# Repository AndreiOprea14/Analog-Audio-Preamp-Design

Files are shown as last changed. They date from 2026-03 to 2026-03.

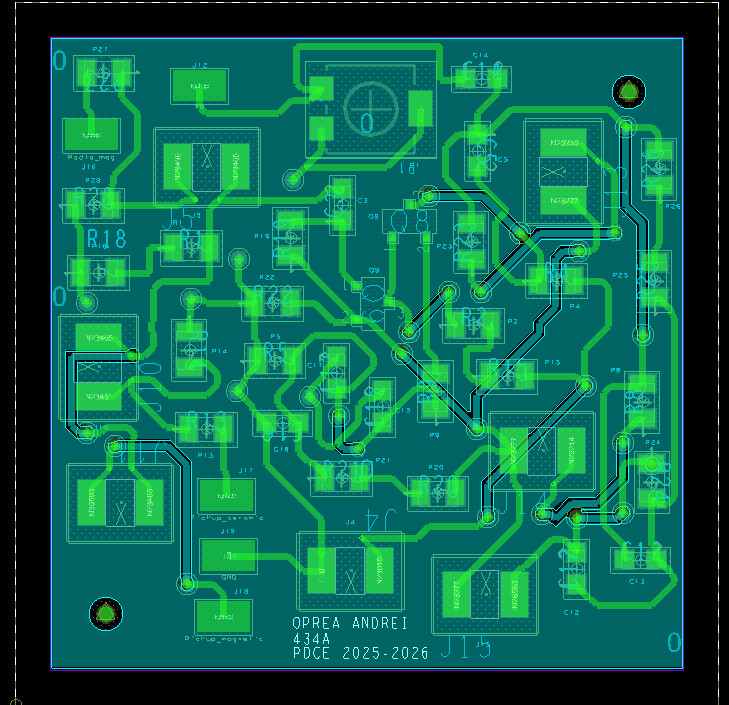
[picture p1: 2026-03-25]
Layout/layout_pcb.jpg

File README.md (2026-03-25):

#  Audio Input Preamplifier & PCB Design

This repository contains the complete design, simulation, and physical layout files for an analog audio input preamplifier with a regulated power supply. It was built as a university hardware project, taking a theoretical schematic all the way to manufacturing-ready files.

## What's this about?
Instead of just doing the math on paper, I had to adapt a base schematic to meet a strictly customized set of parameters (tuning the circuit for a 200mV input sensitivity and a 1000 kOhm input impedance, typical for a ceramic pick-up). 

The engineering process involved:
* **Circuit Simulation:** Before routing anything, I validated the stability and performance of the Class-A amplifier stages using transient and frequency response simulations.
* **Component Substitution:** Swapping out theoretical parts for physically available counterparts (like the BC109C transistors) and making sure the math still checks out.
* **PCB Layout:** Moving from the schematic to **OrCAD PCB Editor**, where I managed trace routing, component placement, and via configurations.

## Tools Used
* **OrCAD Capture CIS** (for schematics and SPICE simulation)
* **OrCAD PCB Editor** (for the physical board layout)

## Project Showcase

schematic

layout_pcb

## What's in this repo?
If you want to check out the technical details, you'll find:
* **Project Documentation:** Detailed math, component choices, and simulation graphs (Transient & Bode plots).
* **Bill of Materials (BOM):** The exact list of resistors, capacitors, transistors, and power supply components used to build the circuit.
* **Gerber Files:** The exported manufacturing files, ready to be sent to a PCB fab.

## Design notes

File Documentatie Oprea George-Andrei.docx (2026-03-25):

Universitatea “Politehnica” din București

Facultatea de Electronică, Telecomunicații si Tehnologia Informației

PROIECT 1:

PREAMPLIFICATOR AUDIO DE INTRARE

CAPITOLUL 5

Student: Oprea George-Andrei

Grupa: 434A

Prof. coordonator

BABARADA Florin

Bucuresti, 2025

1) TEMA DE PROIECTARE

Tema de proiectare prezintă un preamplificator audio de audiofrecvenţă de intrare având schema bloc prezentată în Figura 1. Amplificatorul audio de intrare este compus din o reţea de adaptare la intrare cu principalele surse de semnale audio fiind pick-up cu doză ceramică şi două etaje de amplificare în clasa A, respectiv etajul de intrare şi etajul de ieşire care realizează amplificarea în tensiune a semnalului.

Amplificarea globală a amplificatorului audio de intrare este stabilită de reacţie negativă serie la intrare-paralel la ieşire, iar alimentarea celor 2 etaje de amplificare este realizată de sursa de alimentare.

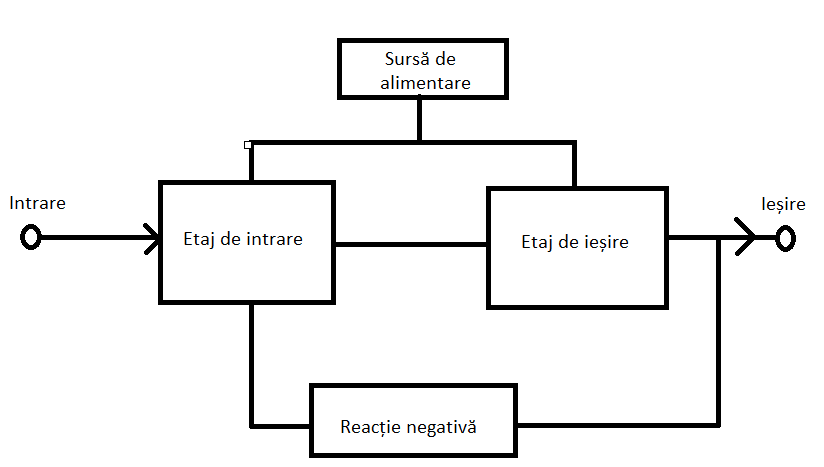
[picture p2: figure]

Figura 1. Schema bloc a preamplificatorului audio de intrare

2) DATE DE INTRARE

Principalii parametrii de intare ai amplificatorului audio sunt:

  - Sensibilitatea minimă la intare Vin (mV)
  - Rezistența de intrare Rin(kOhm)
  - Rezistența de ieșire maximă R0M(kOhm)
  - Tensiunea nominală la ieșirea amplificatorului audio de putere Vn (Vef)

Valorile folosite pentru proiectarea amplificatorului pot fi consultate în tabelul următor:

Nr. crt | Vin [ mV ] | Rin [ kΩ ] | R0M [ kΩ ] | Vn [ Vef ]
12 | 200 | 1000 | 5 | 1,3

3) SCHEMA ELECTRONICĂ

Preamplificatorul este partea care infulențează cel mai pregnant raportul semnal zgomot, caracteristica de frecvență și factorul de distorsiuni într-un lanț de amplificare audiofrecvență.

În practică există adesea și alte semnale numite semnale false, care tind să interfereze cu semnalele dorite și acestea se numesc în general semnale de zgomot.

Un preamplificator sensibil și relativ zgomotos constituie o problemă importantă dacă urmează ca la ieșire zgomotul să fie minim, deoarece orice zgomot din preamplificator este amplificat de fiecare etaj care urmează.

Rețeaua de adaptare la intrare cu diverse surse de semnal este alcătuită din divizoarele R11 și R22.

Amplificarea în tensiune este realizată de etajul de intrare și cel de ieșire. Etajul de intrare este de tip emitor comun cu sarcină distribuită și este realizat cu tranzistorul Q1, iar etajul de ieșire este cuplat galvanic cu etajul de intrare și este de tip emitor comun, realizat cu tranzistorul Q2.

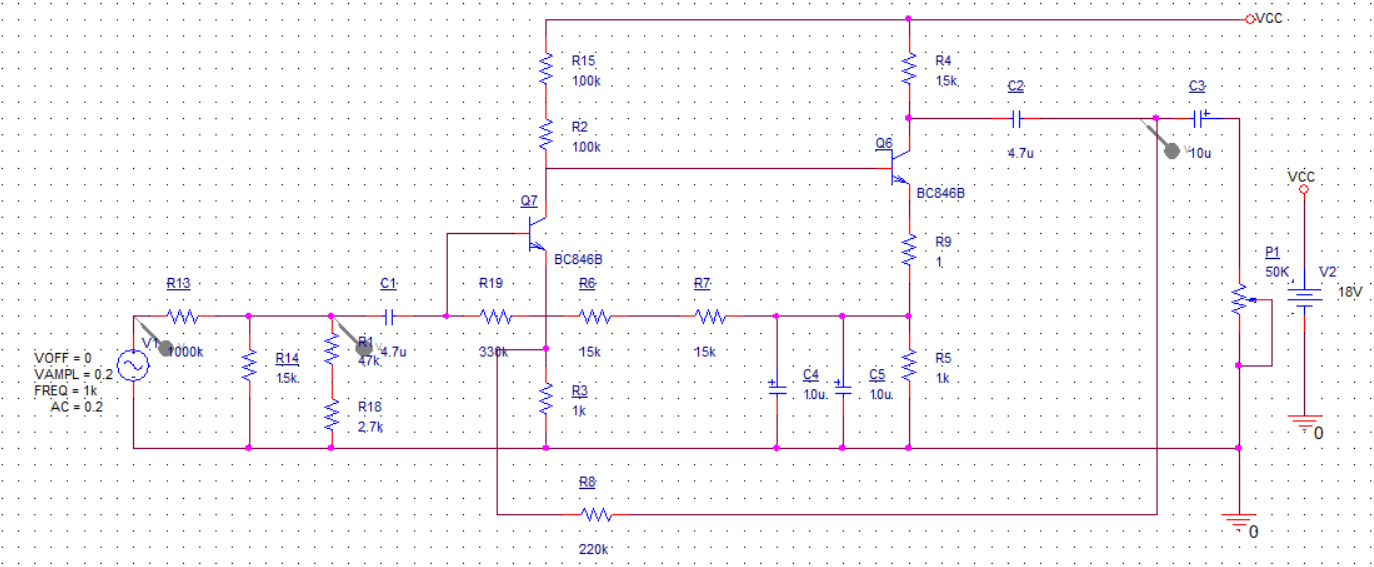
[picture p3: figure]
O imagine care conține text, diagramă, linie, Interval Conținutul generat de inteligența artificială poate fi incorect.

Figura 2. Schema electronica

4) ETAJELE DE AMPLIFICARE

Având în vedere faptul că intrarea amplificatorului de putere necesită la intarre un semnal de amplitudinea de 1,3 Vef, iar amplificatorul corector de ton sau alte etaje intermediare au amplificarea de aproximativ 5, semnalul la ieșirea preamplificatorului de intrare trebuie să aibă o ampltudine de 0,26 Vef, respectiv amplitudinea maximă de 0,42V. Se alege acoperitor o valoare de 0,6V(valoare instantanee maximă). Sensibilitatea la intrare asigură un nivel minim egal cu cel al unui microfon dinamic respectiv 2,5 mV.

I) Alegerea tranzistorilor Q1 și Q2

Nivelul mic al semnalului de intrare impune alegerea pentru etajele de amplificare a unor tranzistoare cu zgomot mic de tip BC846B cu următoarele PSF-uri:

- Q1 : pe baza curbelor izo-F, din catalogul pentru BC846B, se alege Ic1=80μA la care pentru rezistența generatorului R_g =2÷20k⇒F≤2dB . Se alege VCE1≈1,4V. Din catalog în acest PSF rezultă:
- h1E1 ≅ rBE1 ≅ 150kΩ
- hFE1 = β1 ≅ 300
- hOE1 ≅ 18μS
- Q2 : se alege Ic2=1mA și VCE1≈8V. Din catalog în acest PSF rezultă:
- h1E2 ≅ rBE2 ≅ 11kΩ
- hFE2 = β2 ≅ 300
- hOE2 ≅ 1/60 μS

II) Amplificarea în tensiune

Amplificarea în tensiune a etajului de intrare care este de tipul emitor comun cu sarcină distribuită este:

A_(V,Q_1) =-(r_(BE_2) || h_(OE2)^(-1) || (R_2 +R_3 +R_15 ))/(R_4)

Considerând (R_2 +R_3 + R_15 ) ≫r_(BE_2) || h_(OE2)^(-1) →

A_(V,Q_1) =-(r_(BE_2) || h_(OE2)^(-1))/(R_4) = (11k || 60k)/(R_4) = -(9,3k)/(R_4)

Pentru obținerea unor distorsiuni tranzitorii mici se impune o amplificare redusă, cu reacție locală A_(V,Q_1) ≅-10 . Din acest considerent se alege R_3 = 1kΩ.

Din condițiile (R_2 +R_3 +R_15 )≫r_(BE_2) || h_(OE2)^(-1) și V_(CE1) ≅V_(CC) -(R_2 +R_3 +R_4 + R_15 )*I_(c1) ≅1,4V se aleg R_2 +R_3 +R_15 =202kΩ și V_(cc) =18V.

Luând în considerare filtrul RC și componenetele disponibile alegem R_2 + R_15 = 200kΩ și C_1 = 4,7 μF.

Ecuația dreptei de sarcină pentru Q2: V_(CC) =(R_5 +R_4 +R_9 )*I_(c2) +V_(CE2) →

R_4 ≅(V_(CC) -V_(R9) -V_(CE2))/(I_(C2))=(18-0,743-7.1)/(0,767) V/(mA)=16,65kΩ

Având în vedere valorile disponibile se adoptă R_4 = 15kΩ

Amplificarea în tensiune a etajelor de ieșire este:

A_(V,Q2) =-(β_2 (R_4 ||h_(OE2)^(-1) ))/(h_(OE_1)^(-1) +r_(BE_2)) = -48,5

Amplificarea în tensiune a etajului de intrare este:

A_(V,Q_1) =-(β_1 (r_(BE_1) || h_(OE2)^(-1) )||(R_2 +R_3 + R_15 ))/(r_(BE_1) +(β_1 +1)*R_4)=-8.6

Amplificarea în tensiune a preamplificatorului în buclă deschisă este:

A_V =A_(V,Q1) *A_(V,Q2) =417,1

III) Impedanta de intrare

Impedanța de intrare în bulcă deschisă a preamplificatorului este:

Z_(inT1) =(r_(BE1) +(β_1 +1)*R_3 )||R_19 + R_6 + R_(7))

R serie se dimensionează având în vedere necesitatea polarizării bazei tranzistorului Q1:

R_(serie) *I_(B1) =V_(R5) -V_(BE1) -V_(R3) și aproximând V_(BE1) =0,55V →

R_(serie) =(I_(E2) *R_5 -V_(BE1) -I_(E1) *R_3)/(I_(B1))=362,48kΩ se alege R_(serie) =360kΩ

Z_(inT1) =(150k+301k)360k=200kΩ

IV) Dimensionarea condensatorilor

Din motive de stabilitate determinate grafic pe caracteristica BODE, se alege pentru polul dat de C_4 la frecvența f_4 ≅50÷100Hz(75Hz)

Rezistența văzută la bornele C_4 si C_5 este:

R_(C4, C5) =R_5 ||(r_(BE2) +(R_2 +R_3 +R_15 )||h_(OE1)^(-1))/(β_2)=375Ω

C_(4,5) ≅1/(2*Π*f_2 *R_(C2))=21,2μF și se alege C_4 =10μ F , C_5 = 10μ F

Având în vedere că R_1 se alege astfel încât impedanța văzută spre amplificator să fie ≅47k , necesară pentru adaptarea cu doza magnetică și alegând f_1 =0,6Hz →

C_1 =1/(2*Π*f_1 *47*10^3)=5,6 μF

Deci, C_1 =4,7 μF . Pentru dimensionarea C2 se apreciază că impedanța la bornele sale nu va fi mai mică de 50kΩ având în vedere efectul potențiometrului de balans și al rețelei de reacție. Se alege f_2 =0,7Hz→C_2 =1/(2*Π*f_2 *50*10^3)=5,3μF și se alege C_2 =4,7 μF .

Imepdanța de ieșire a preamplificatorului fără reacție negativă este:

Z_(out) =R_5 ||h_(OE2)^(-1) =12kΩ

Cu reacția negativă având în vedere necesitatea de amplificare pentru o valoare medie β_r =100^(-1) → impedanța de la ieșire: Z_(out,A) =(Z_(OUT))/(β_r *A_v)=3,02 kΩ

Valoarea lui C3 s-a ales de C3=10μF.

V) Reacția negativă și rețelele de adaptare

Pentru estimarea nivelului nominal al semnalului la ieşirea preamplificatorului cunoaştem:

Pentru estimarea nivelului nominal al semnalului la ieşirea preamplificatorului cunoaştem:

- Amplitudinea nominală a semnalului la intrarea în amplificatorul final

Vnom. aap = 1,3Vef

- Amplificarea circuitelor intermediare de aproximativ 5
- Atenuarea introdusă de P1 = 0,9

V_(out,pa) =(1,3V_(ef))/(5*0,9) =288,8mVef

Reţelele de adaptare se dimensionează în raport cu acest nivel şi nivelele tipice ale surselor de program. S-au adoptat următoarele categorii de surse de semnal corespunzătoare cu tema de proiectare:

Sursa | Rezistenţa de intrare Ri (KΩ) | Sensibilitate Vin (mV)
Pick-up ceramic | 1MΩ | 200mVef

Alegerea reţelei de reacţie serie la intrare–paralel la ieşire creşte impedanţa de intrare şi micşorează impedanţa de ieşire, apropiind preamplificatorul audio de intrare de un amplificator ideal de tensiune. Experimental pentru un răspuns tranzitoriu bun .

Pentru poziţia microfon şi pick-up ceramic se utilizează reţeaua de reacţie, R_8 -R_3 .

Amplificatorul se calculează pentru nivelul minim de intrare dat de microfon:

A_(VR) =(A_V)/(1+β_r *A_V)=(V_(iesire))/(V_(intrare))=(288,8mV)/(200mV)=1,44

β_r =(A_v -1,44)/(1,44*A_v)=0,69

dar β_r =(R_3)/(R_8 +R_3)≈(R_3)/(R_8) ⇒ R_8 ≈(R_3)/(β_r)=221kΩ . Se alege R_8 =220kΩ .

Dimensionarea divizorului de intrare pentru pick-up ceramic.

(R_13)/(R_14)≈(V_(in))/(V_(inT1))=(200mV)/(2,5mV)=80

Din condiţia ca impedanţa de intrare să fie de aproximativ 1MΩ, se alege R_13 =1MΩ⇒ R_14 ≈12,5kΩ . Se alege R14=15kΩ

5) SIMULAREA FUNCTIONALITATII

Simularea preamplificatorului audio de intrare s-a făcut din punct de vedere al PSF-ului, al analizei tranzitorii și al răspunsului în frecvență. Simularea PSF-ului ne dă o bună concordanță cu datele de proiectare respectiv curenții de colector și tensiunile colector-emitor.

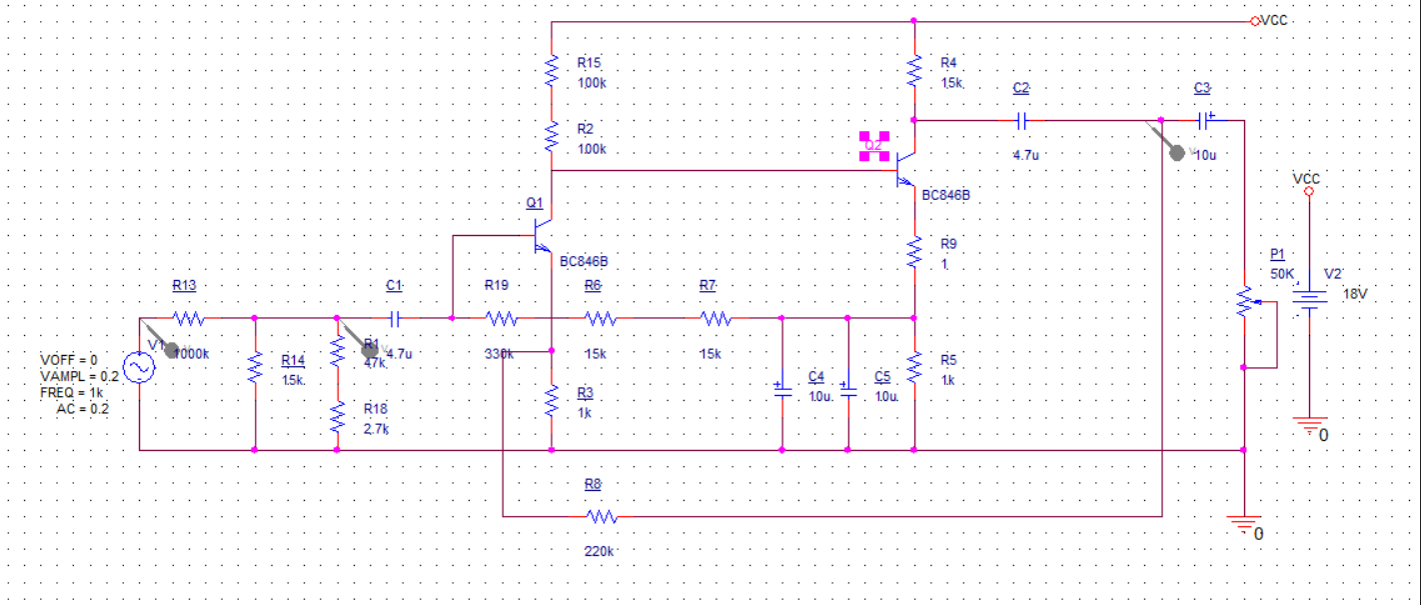
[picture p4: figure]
O imagine care conține text, diagramă, linie, Interval Conținutul generat de inteligența artificială poate fi incorect.

Simulare tranzitoriu

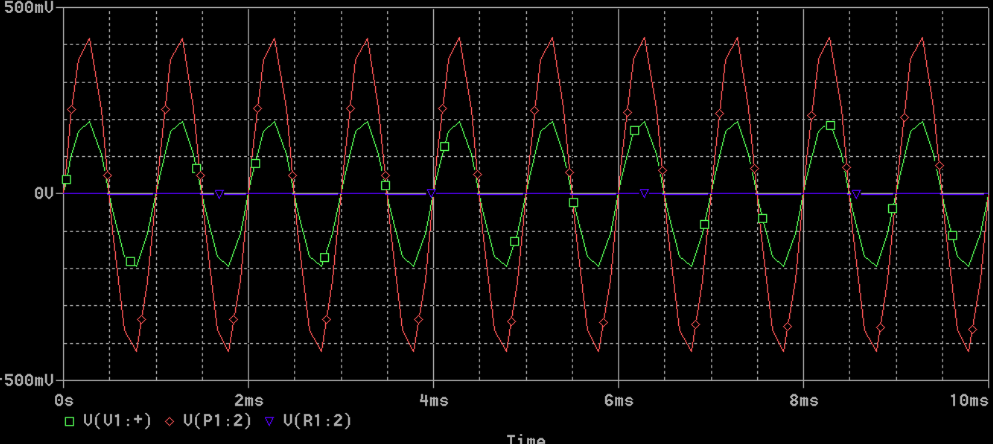
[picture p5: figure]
O imagine care conține captură de ecran Conținutul generat de inteligența artificială poate fi incorect.

Simulare frecventa

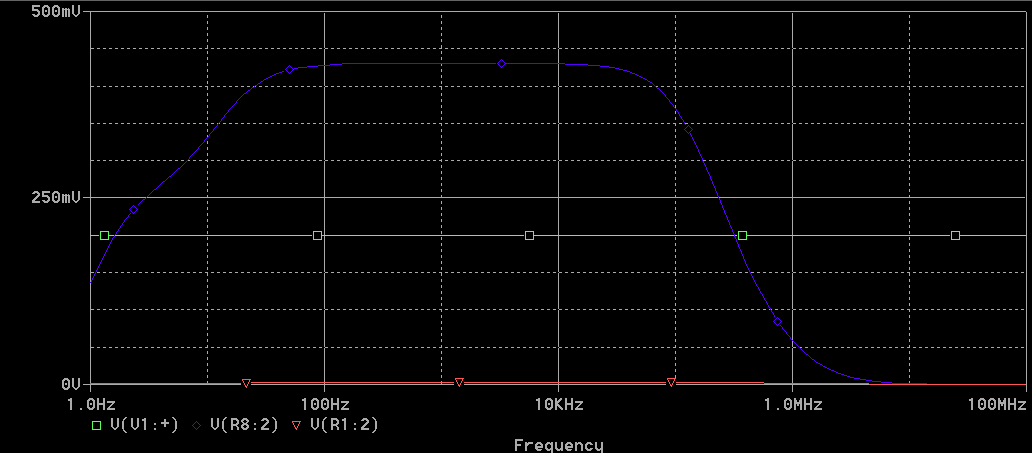
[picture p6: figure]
O imagine care conține captură de ecran, text, diagramă, linie Conținutul generat de inteligența artificială poate fi incorect.

6) LISTA COMPONENTELOR

Rezistente:

R2 = 100kΩ ± 5%

R3 = 1k Ω ± 5%

R4 = 15kΩ ± 5%

R19 = 330k Ω ± 5%

R15 = 100kΩ ± 5%

R7 = 15k Ω ± 5%

P1 = 50kΩ

R6 = 15k Ω ± 5%

R9 = 1Ω ± 5%

R5 = 1k Ω ± 5%

R13 = 1000kΩ ± 5%

R8 = 220k Ω ± 5%

R14 = 15kΩ ± 5%

R1 = 47kΩ ± 5%

R18 = 2.7kΩ ± 5%

Condensatoare:

C2 = 4.7u ± 10%

C3 = 10u ± 20%

C5 = 10u ± 20%

C4 = 10u ± 20%

C1 = 4.7u ± 10%

Tranzistori: Q1 = BC846B Q2 = BC846B

7) ACTUALIZARE ETAPA 2

S-au adaugat condesnsatorii de 4.7u in locul celor de 10uF polarizati pentru a elibera spatiu pe placuta PCB acolo unde a fost nevoie. S-au adaugat conectori pentru ground, alimentare si conectarea circuitului in functie de intrare. Mai jos se gaseste schema actualiazata complet si schema in PCB. Se gasesc de asemenea si poze cu simularile atat in regim tranzitoriu, cat si in frecventa, realizate cu circuitul actualizat.

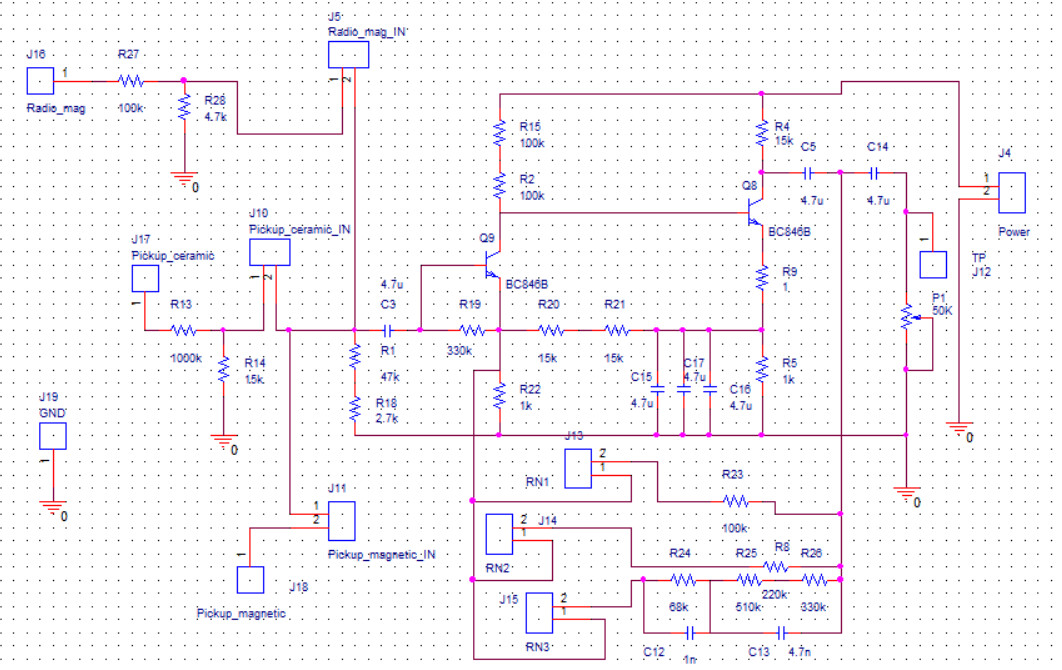
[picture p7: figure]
O imagine care conține text, diagramă, Plan, linie Conținutul generat de inteligența artificială poate fi incorect.
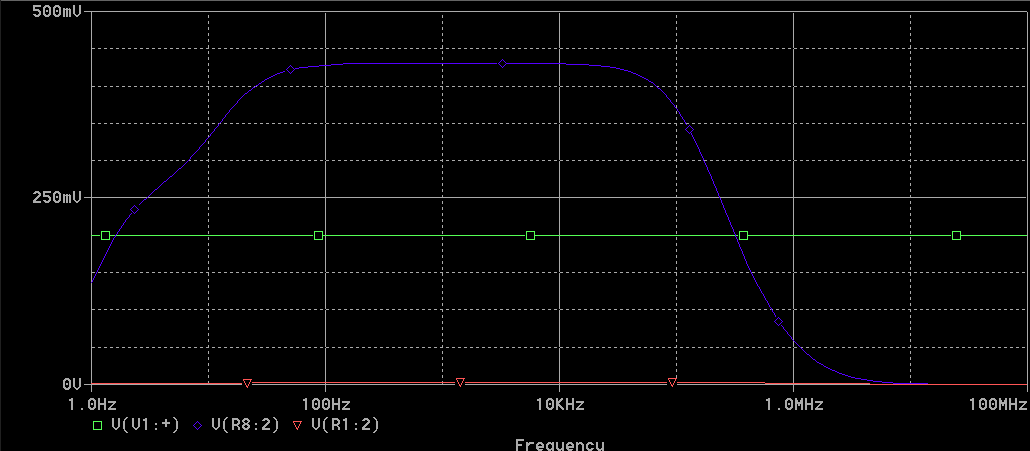
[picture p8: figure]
O imagine care conține captură de ecran, text, diagramă, Interval Conținutul generat de inteligența artificială poate fi incorect.
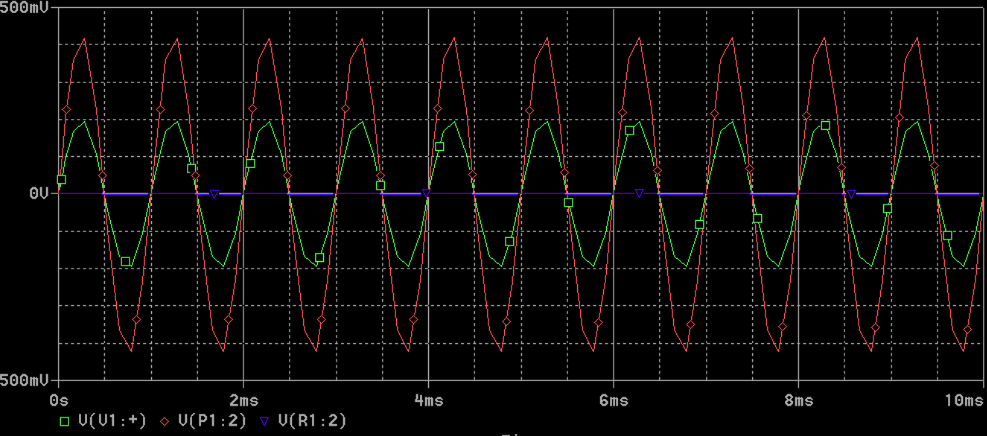
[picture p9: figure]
O imagine care conține captură de ecran Conținutul generat de inteligența artificială poate fi incorect.
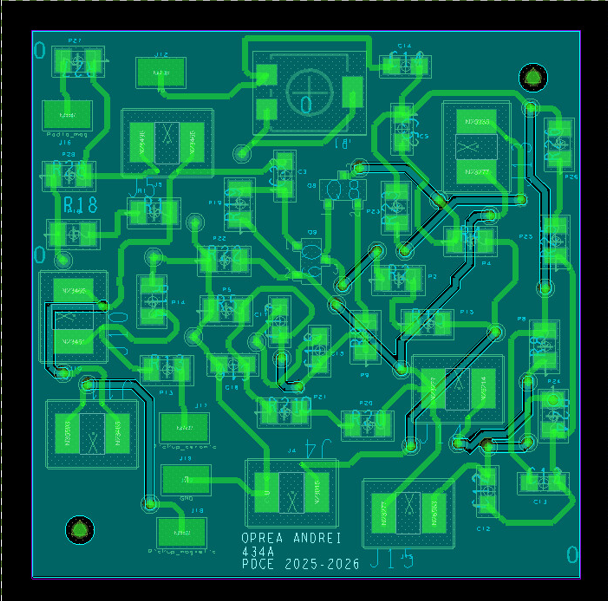
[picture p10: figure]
O imagine care conține captură de ecran, afișaj, circuit Conținutul generat de inteligența artificială poate fi incorect.

Schema in GerbViewer:

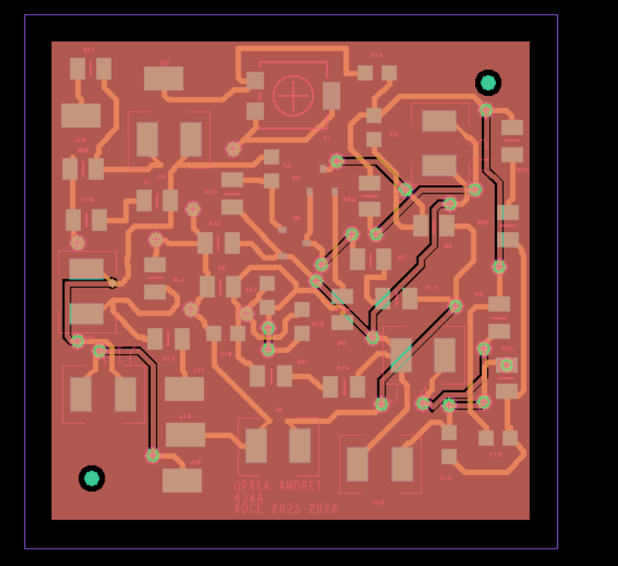
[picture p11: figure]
O imagine care conține ceas, captură de ecran Conținutul generat de inteligența artificială poate fi incorect.

BIBLIOGRAFIE

Florin BABARADA, „Proiectarea circuitelore electronice de audiofrecvență”,

Editura Printech, 2003

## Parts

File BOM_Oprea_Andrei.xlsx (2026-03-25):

Nr. Crt. | Nume | Catalog | Cod distrib | Nume prod | Prod | Clasă | Descriere | Distribuitor | Cantitate
3 | 1 | (LINK) (https://www.tme.eu/ro/details/smd0805-1r/rezistente-smd-0805/royal-ohm/0805s8j010jt5e/) | SMD0805-1R-5% | 0805S8J010JT5E | ROYAL OHM | rezistor | Rezistor SMD, chip, 0805, 1Ω, ±5%, 0.125W | TME România | 1
20 | 1k | (LINK) (https://www.tme.eu/ro/details/smd0805-1k/rezistente-smd-0805/royal-ohm/0805s8j0102t5e/) | SMD0805-1K-5% | 0805S8J0102T5E | ROYAL OHM | rezistor | Rezistor SMD, chip, 0805, 1kΩ, ±5%, 0.125W | TME România | 2
25 | 2.7k | (LINK) (https://www.tme.eu/ro/details/smd0805-2k7/rezistente-smd-0805/royal-ohm/0805s8j0272t5e/) | SMD0805-2K7-5% | 0805S8F2701T5E | ROYAL OHM | rezistor | Rezistor SMD, chip, 0805, 2.7kΩ, ±5%, 0.125W | TME România | 1
28 | 4.7k | (LINK) (https://www.tme.eu/ro/details/smd0805-4k7/rezistente-smd-0805/royal-ohm/0805s8j0472t5e/) | SMD0805-4K7-5% | 0805S8J0472T5E | ROYAL OHM | rezistor | Rezistor SMD, chip, 0805, 4.7kΩ, ±5%, 0.125W | TME România | 1
34 | 15k | (LINK) (https://www.tme.eu/ro/details/smd0805-15k/rezistente-smd-0805/royal-ohm/0805s8j0153t5e/) | SMD0805-15K-5% | 0805S8J0153T5E | ROYAL OHM | rezistor | Rezistor SMD, chip, 0805, 15kΩ, ±5%, 0.125W | TME România | 4
36 | 47k | (LINK) (https://www.tme.eu/ro/details/smd0805-22k/rezistente-smd-0805/royal-ohm/0805s8j0223t5e/) | SMD0805-47K-5% | 0805S8J0473T5E | ROYAL OHM | rezistor | Rezistor: thick film; SMD; 0805; 47kΩ; 0,125W; ±5%; -55÷125°C | TME România | 1
37 | 68k | (LINK) (https://www.tme.eu/ro/details/smd0805-68k/rezistente-smd-0805/royal-ohm/0805s8j0683t5e/) | SMD0805-68K-5% | 0805S8J0683T5E | ROYAL OHM | rezistor | Rezistor SMD, chip, 0805, 68kΩ, ±5%, 0.125W | TME România | 1
38 | 100k | (LINK) (https://www.tme.eu/ro/details/smd0805-100k/rezistente-smd-0805/royal-ohm/0805s8j0104t5e/) | SMD0805-100K-5% | 0805S8J0104T5E | ROYAL OHM | rezistor | Rezistor SMD, chip, 0805, 100kΩ, ±5%, 0.125W | TME România | 4
41 | 220k | (LINK) (https://www.tme.eu/ro/details/smd0805-220k/rezistente-smd-0805/royal-ohm/0805s8j0224t5e/) | SMD0805-220K-5% | 0805S8J0224T5E | ROYAL OHM | rezistor | Rezistor SMD, chip, 0805, 220kΩ, ±5%, 0.125W | TME România | 1
42 | 330k | (LINK) (https://www.tme.eu/ro/details/smd0805-330k/rezistente-smd-0805/royal-ohm/0805s8j0334t5e/) | SMD0805-330K-5% | 0805S8J0334T5E | ROYAL OHM | rezistor | Rezistor SMD, chip, 0805, 330kΩ, ±5%, 0.125W | TME România | 2
44 | 510k | (LINK) (https://www.tme.eu/ro/details/smd0805-510k/rezistente-smd-0805/royal-ohm/0805s8j0514t5e/) | SMD0805-510K-5% | 0805S8J0514T5E | ROYAL OHM | rezistor | Rezistor SMD, chip, 0805, 510kΩ, ±5%, 0.125W | TME România | 1
45 | 1M | (LINK) (https://www.tme.eu/ro/details/crcw08051m00jntabc/rezistente-smd-0805/vishay/) | SMD0805-1M-5% | CRCW08051M00JNTABC | VISHAY | rezistor | Rezistor SMD, chip, 0805, 1MΩ, ±5%, 0.125W | TME România | 1
54 | 50k | (LINK) (http://www.tme.eu/ro/details/3314g-1-503e/trimere-smd-cu-o-singura-tura/bourns/) | 3314G-1-503E | 3314G-1-503E | BOURNS | potențiometru | Potențiome-tru liniar, simplă tură, SMD, 50kΩ, ±20%, 100ppm/°C, 0.25W | TME România | 1
62 | 1nF | (LINK) (https://www.tme.eu/ro/details/cc0805jrnpo9102/condensatoare-mlcc-smd/yageo/cc0805jrnpo9bn102/) | CL21C102JBCNNNC | CL21C102JBCNNNC | SAMSUNG | condensator | Condensator MLCC, SMD, 0805, 1nF, ±5%, 50V, C0G | TME România | 1
64 | 4.7nF | (LINK) (https://www.tme.eu/ro/details/cl21b472kbannnc/condensatoare-mlcc-smd-0805/samsung/) | CL21B472KBANNNC | CL21B472KBANNNC | SAMSUNG | condensator | Condensator MLCC, SMD, 0805, 4.7nF, ±5%, 50V, X7R | TME România | 1
75 | 4.7uF | (LINK) (https://www.tme.eu/ro/details/cl21a475kaqnnng/condensatoare-mlcc-smd-0805/samsung/) | CL21A475KAQNNNG | CL21A475KAQNNNG | SAMSUNG | condensator | ceramic; MLCC; 4,7uF; 25V; X5R; ±10%; SMD; 0805 | TME România | 6
87 | NPN | (LINK) (https://www.tme.eu/ro/details/bc846b-dio/tranzistori-smd-npn/diotec-semiconductor/bc846b/) | BC846B | BC846B | DIOTEC | tranzistor bipolar | Tranzistor bipolar NPN, SMD, SOT23, 65V, 100mA | TME România | 2
